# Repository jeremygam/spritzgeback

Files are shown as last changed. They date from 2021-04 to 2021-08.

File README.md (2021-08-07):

# Spritzgeback
A suite of similar custom low profile mechanical keyboards running qmk

Note that this documentation is a work in progress. Will update with more and clean up later






### Basic Information

There are three variants of the spritzgeback keyboard: one with square spacing between keys, one with rectangular spacing between keys, and one with rectangular spacing that uses hotswap sockets.

Square:
Uses three laser-cut case layers plus a PCB layer. All layers are simply stacked so each is visible from the side. This keyboard should be best if using Kailh Choc v2 switches with more 'regular' profile keycaps like DSA, or if you generally prefer wider spacing between keys. Note that if you are using high profile keycaps, the keys may not depress all the way if you include the plate (case layer 3) - it should be fine to leave out layer 3 and just have the PCB as the top layer

Rect:
Uses four laser-cut case layers, with the PCB residing within one of the layers. This keyboard should be best if using Kailh Choc v1 switches with either the Kailh keycaps or MBK keycaps (which measure 16mm in height and 17mm in width).

Hotswap:
Similar to Rect but uses hotswap sockets instead of having switches soldered in place.

### Making a keyboard

If all you want to do is make one of these keyboards, just download the gerber files within the gerber_files directory and the eps files within the case_files directory. You can send the gerber files for production from a PCB manufacturing company. Note that the ".gml" file might need to be renamed to ".gm1" and the ".txt" file might need to be renamed to ".drl" depending on the company. The eps files can be directly sent for laser cutting. Double check that the dimensions are correct before submitting (315.6mm x 96mm for square, 308.9mm x 91.75mm for rect). Also note that the combined thickness of the PCB plus layer 2 should be at least 3mm (preferably a bit more for tolerance) to allow the switch pins adequate space within the case sandwich. For example, with a 1.6mm thick PCB, layer 2 should be at least 1.5mm or so thick. For keyboards where the PCB is totally enclosed in the case (i.e. rect and hotswap), layer 3 should be at least as thick as the PCB so that there isn't a gap between case layers.

Once all components except switches have been soldered, flash the keyboard with qmk (https://beta.docs.qmk.fm/tutorial/newbs_flashing), making sure to short the two "reset" holes while plugging in the PCB. After flashing, test the entire circuit by shorting out the switch holes and making sure the appropriate key is registered. Following that, switches or sockets can then be soldered in. The main step for case assembly is insertion of the threaded inserts into the case layers. If using acrylic, be careful not to crack the layers while inserting the threaded inserts - using the heat from a soldering iron to melt the plastic is highly recommended over using force. If using wood or bamboo layers, a hammer or mallet should be fine. The keyboard can then be screwed together, making sure not to overtighten the screws.

### BOM

Fill in later. See schematic for now

### Requirements

You will need to install and use qmk to flash your keyboard firmware https://qmk.fm/

You will need a footprint file for the USB-C connector Korean Hroparts Elec TYPE-C-31-M-17 from https://www.snapeda.com/parts/TYPE-C-31-M-12/HRO%20Electronics%20Co.,%20Ltd./view-part/

You may also want footprints for Kailh Choc v1 switches (PG1350) from https://github.com/daprice/keyswitches.pretty (also under CC BY-SA 4.0). I modified some of those original footprints to allow for either Choc v1 or v2 switches to be used (see SW_PG1353.kicad_mod and Kailh_socket_PG1353.kicad_mod in the JJG.pretty directory).

### Other Information

For info on how to design your own keyboard, check out Hadi's youtube channel (https://www.youtube.com/playlist?list=PLbtY7JsOJDYkHNuTmBtGgaWv_qipKeL-u) or Masterzen's tutorial (https://www.masterzen.fr/2020/05/03/designing-a-keyboard-part-1/)

Note that since each of the spritzgeback variants are highly similar electrically, they can all use the same qmk files

Note that if you make your own case files, ponoko recommends saving in eps file format with units set to mm instead of points.

------------------------



This work is licensed under a [Creative Commons Attribution-ShareAlike 4.0 International License](http://creativecommons.org/licenses/by-sa/4.0/).

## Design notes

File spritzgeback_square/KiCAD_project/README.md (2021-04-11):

note that I wanted to rename the project from CHOCOBOard to spritzgeback, but KiCAD doesn't handle renaming easily so I've kept the original name here

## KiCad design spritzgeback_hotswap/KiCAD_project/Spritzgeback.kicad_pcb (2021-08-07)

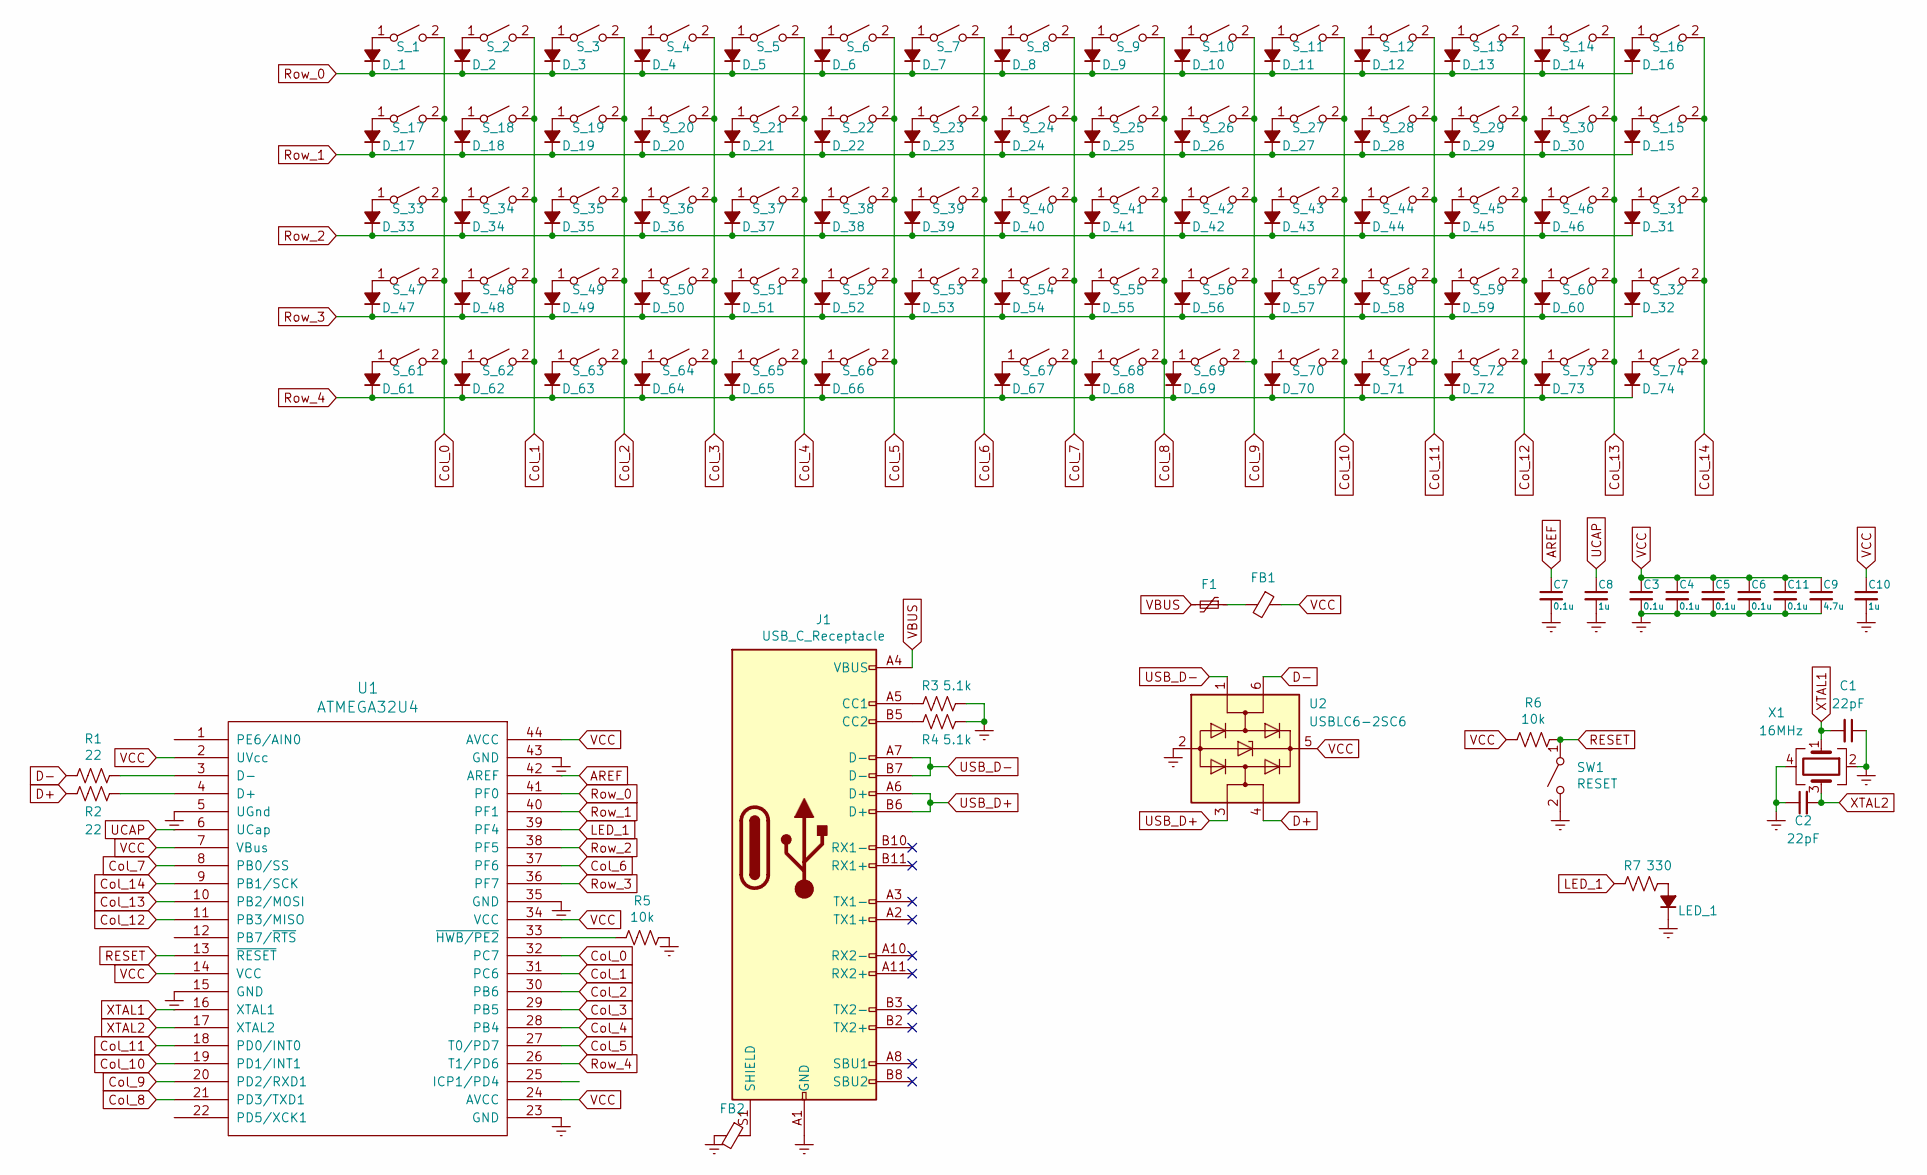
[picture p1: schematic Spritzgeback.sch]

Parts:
C1, C2: 22pF; C_0805_2012Metric_Pad1.18x1.45mm_HandSolder
C3, C4, C5, C6, C7, C11: 0.1u; C_0805_2012Metric_Pad1.18x1.45mm_HandSolder
C8, C10: 1u; C_0805_2012Metric_Pad1.18x1.45mm_HandSolder
C9: 4.7u; C_0805_2012Metric_Pad1.18x1.45mm_HandSolder
D_1, D_2, D_3, D_4, D_5, D_6, D_7, D_8, D_9, D_10, D_11, D_12, D_13, D_14, D_15, D_16, D_17, D_18, D_19, D_20, D_21, D_22, D_23, D_24, D_25, D_26, D_27, D_28, D_29, D_30, D_31, D_32, D_33, D_34, D_35, D_36, D_37, D_38, D_39, D_40, D_41, D_42, D_43, D_44, D_45, D_46, D_47, D_48, D_49, D_50, D_51, D_52, D_53, D_54, D_55, D_56, D_57, D_58, D_59, D_60, D_61, D_62, D_63, D_64, D_65, D_66, D_67, D_68, D_69, D_70, D_71, D_72, D_73, D_74: D_Small_ALT; D_SOD-123_silk
F1: Polyfuse_Small; R_0805_2012Metric
FB1, FB2: Ferrite_Bead_Small; R_0805_2012Metric
J1: USB_C_Receptacle; HRO_TYPE-C-31-M-12
LED_1: D_Small_ALT; LED_0805_2012Metric
R1, R2: 22; R_0805_2012Metric_Pad1.20x1.40mm_HandSolder
R3, R4: 5.1k; R_0805_2012Metric
R5, R6: 10k; R_0805_2012Metric_Pad1.20x1.40mm_HandSolder
R7: 330; R_0805_2012Metric_Pad1.20x1.40mm_HandSolder
SW1: RESET; reset_holes
S_1, S_2, S_3, S_4, S_5, S_6, S_7, S_8, S_9, S_10, S_11, S_12, S_13, S_14, S_15, S_16, S_17, S_18, S_19, S_20, S_21, S_22, S_23, S_24, S_25, S_26, S_27, S_28, S_29, S_30, S_31, S_32, S_33, S_34, S_35, S_36, S_37, S_38, S_39, S_40, S_41, S_42, S_43, S_44, S_45, S_46, S_47, S_48, S_49, S_50, S_51, S_52, S_53, S_54, S_55, S_56, S_57, S_58, S_59, S_60, S_61, S_62, S_63, S_64, S_65, S_66, S_67, S_68, S_69, S_70, S_71, S_72, S_73, S_74: SW_SPST; Kailh_socket_PG1353
U1: ATMEGA32U4; TQFP-44_10x10mm_P0.8mm
U2: USBLC6-2SC6; SOT-23-6
X1: 16MHz; Crystal_SMD_3225-4Pin_3.2x2.5mm

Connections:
AREF: C7.1, U1.42 (AREF)
Col_0: S_1.2 (B), S_17.2 (B), S_33.2 (B), S_47.2 (B), S_61.2 (B), U1.32 (PC7)
Col_1: S_2.2 (B), S_18.2 (B), S_34.2 (B), S_48.2 (B), S_62.2 (B), U1.31 (PC6)
Col_2: S_3.2 (B), S_19.2 (B), S_35.2 (B), S_49.2 (B), S_63.2 (B), U1.30 (PB6)
Col_3: S_4.2 (B), S_20.2 (B), S_36.2 (B), S_50.2 (B), S_64.2 (B), U1.29 (PB5)
Col_4: S_5.2 (B), S_21.2 (B), S_37.2 (B), S_51.2 (B), S_65.2 (B), U1.28 (PB4)
Col_5: S_6.2 (B), S_22.2 (B), S_38.2 (B), S_52.2 (B), S_66.2 (B), U1.27 (T0/PD7)
Col_6: S_7.2 (B), S_23.2 (B), S_39.2 (B), S_53.2 (B), U1.37 (PF6)
Col_7: S_8.2 (B), S_24.2 (B), S_40.2 (B), S_54.2 (B), S_67.2 (B), U1.8 (PB0/SS)
Col_8: S_9.2 (B), S_25.2 (B), S_41.2 (B), S_55.2 (B), S_68.2 (B), U1.21 (PD3/TXD1)
Col_9: S_10.2 (B), S_26.2 (B), S_42.2 (B), S_56.2 (B), S_69.2 (B), U1.20 (PD2/RXD1)
Col_10: S_11.2 (B), S_27.2 (B), S_43.2 (B), S_57.2 (B), S_70.2 (B), U1.19 (PD1/INT1)
Col_11: S_12.2 (B), S_28.2 (B), S_44.2 (B), S_58.2 (B), S_71.2 (B), U1.18 (PD0/INT0)
Col_12: S_13.2 (B), S_29.2 (B), S_45.2 (B), S_59.2 (B), S_72.2 (B), U1.11 (PB3/MISO)
Col_13: S_14.2 (B), S_30.2 (B), S_46.2 (B), S_60.2 (B), S_73.2 (B), U1.10 (PB2/MOSI)
Col_14: S_15.2 (B), S_16.2 (B), S_31.2 (B), S_32.2 (B), S_74.2 (B), U1.9 (PB1/SCK)
D+: R2.2, U2.4 (I/O2)
D-: R1.2, U2.6 (I/O1)
Earth: C1.1, C2.1, C3.2, C4.2, C5.2, C6.2, C7.2, C8.2, C9.2, C10.2, C11.2, FB2.2, J1.A1 (GND), J1.A12 (GND), J1.B1 (GND), J1.B12 (GND), LED_1.1 (K), R3.1, R4.1, R5.1, SW1.2 (B), U1.5 (UGnd), U1.15 (GND), U1.23 (GND), U1.35 (GND), U1.43 (GND), U2.2 (GND), X1.2, X1.4; also elsewhere on the board
LED_1: R7.2, U1.39 (PF4)
unnamed: D_1.2 (A), S_1.1 (A)
unnamed: D_2.2 (A), S_2.1 (A)
unnamed: D_3.2 (A), S_3.1 (A)
unnamed: D_4.2 (A), S_4.1 (A)
unnamed: D_5.2 (A), S_5.1 (A)
unnamed: D_6.2 (A), S_6.1 (A)
unnamed: D_7.2 (A), S_7.1 (A)
unnamed: D_8.2 (A), S_8.1 (A)
unnamed: D_9.2 (A), S_9.1 (A)
unnamed: D_10.2 (A), S_10.1 (A)
unnamed: D_11.2 (A), S_11.1 (A)
unnamed: D_12.2 (A), S_12.1 (A)
unnamed: D_13.2 (A), S_13.1 (A)
unnamed: D_14.2 (A), S_14.1 (A)
unnamed: D_15.2 (A), S_15.1 (A)
unnamed: D_16.2 (A), S_16.1 (A)
unnamed: D_17.2 (A), S_17.1 (A)
unnamed: D_18.2 (A), S_18.1 (A)
unnamed: D_19.2 (A), S_19.1 (A)
unnamed: D_20.2 (A), S_20.1 (A)
unnamed: D_21.2 (A), S_21.1 (A)
unnamed: D_22.2 (A), S_22.1 (A)
unnamed: D_23.2 (A), S_23.1 (A)
unnamed: D_24.2 (A), S_24.1 (A)
unnamed: D_25.2 (A), S_25.1 (A)
unnamed: D_26.2 (A), S_26.1 (A)
unnamed: D_27.2 (A), S_27.1 (A)
unnamed: D_28.2 (A), S_28.1 (A)
unnamed: D_29.2 (A), S_29.1 (A)
unnamed: D_30.2 (A), S_30.1 (A)
unnamed: D_31.2 (A), S_31.1 (A)
unnamed: D_32.2 (A), S_32.1 (A)
unnamed: D_33.2 (A), S_33.1 (A)
unnamed: D_34.2 (A), S_34.1 (A)
unnamed: D_35.2 (A), S_35.1 (A)
unnamed: D_36.2 (A), S_36.1 (A)
unnamed: D_37.2 (A), S_37.1 (A)
unnamed: D_38.2 (A), S_38.1 (A)
unnamed: D_39.2 (A), S_39.1 (A)
unnamed: D_40.2 (A), S_40.1 (A)
unnamed: D_41.2 (A), S_41.1 (A)
unnamed: D_42.2 (A), S_42.1 (A)
unnamed: D_43.2 (A), S_43.1 (A)
unnamed: D_44.2 (A), S_44.1 (A)
unnamed: D_45.2 (A), S_45.1 (A)
unnamed: D_46.2 (A), S_46.1 (A)
unnamed: D_47.2 (A), S_47.1 (A)
unnamed: D_48.2 (A), S_48.1 (A)
unnamed: D_49.2 (A), S_49.1 (A)
unnamed: D_50.2 (A), S_50.1 (A)
unnamed: D_51.2 (A), S_51.1 (A)
unnamed: D_52.2 (A), S_52.1 (A)
unnamed: D_53.2 (A), S_53.1 (A)
unnamed: D_54.2 (A), S_54.1 (A)
unnamed: D_55.2 (A), S_55.1 (A)
unnamed: D_56.2 (A), S_56.1 (A)
unnamed: D_57.2 (A), S_57.1 (A)
unnamed: D_58.2 (A), S_58.1 (A)
unnamed: D_59.2 (A), S_59.1 (A)
unnamed: D_60.2 (A), S_60.1 (A)
unnamed: D_61.2 (A), S_61.1 (A)
unnamed: D_62.2 (A), S_62.1 (A)
unnamed: D_63.2 (A), S_63.1 (A)
unnamed: D_64.2 (A), S_64.1 (A)
unnamed: D_65.2 (A), S_65.1 (A)
unnamed: D_66.2 (A), S_66.1 (A)
unnamed: D_67.2 (A), S_67.1 (A)
unnamed: D_68.2 (A), S_68.1 (A)
unnamed: D_69.2 (A), S_69.1 (A)
unnamed: D_70.2 (A), S_70.1 (A)
unnamed: D_71.2 (A), S_71.1 (A)
unnamed: D_72.2 (A), S_72.1 (A)
unnamed: D_73.2 (A), S_73.1 (A)
unnamed: D_74.2 (A), S_74.1 (A)
unnamed: F1.1, FB1.2
unnamed: FB2.1, J1.S1 (SHIELD)
unnamed: J1.A5 (CC1), R3.2
unnamed: J1.B5 (CC2), R4.2
unnamed: LED_1.2 (A), R7.1
unnamed: R1.1, U1.3 (D-)
unnamed: R2.1, U1.4 (D+)
unnamed: R5.2, U1.33 (~HWB/PE2)
RESET: R6.1, SW1.1 (A), U1.13 (~RESET); also elsewhere on the board
Row_0: D_1.1 (K), D_2.1 (K), D_3.1 (K), D_4.1 (K), D_5.1 (K), D_6.1 (K), D_7.1 (K), D_8.1 (K), D_9.1 (K), D_10.1 (K), D_11.1 (K), D_12.1 (K), D_13.1 (K), D_14.1 (K), D_16.1 (K), U1.41 (PF0)
Row_1: D_15.1 (K), D_17.1 (K), D_18.1 (K), D_19.1 (K), D_20.1 (K), D_21.1 (K), D_22.1 (K), D_23.1 (K), D_24.1 (K), D_25.1 (K), D_26.1 (K), D_27.1 (K), D_28.1 (K), D_29.1 (K), D_30.1 (K), U1.40 (PF1)
Row_2: D_31.1 (K), D_33.1 (K), D_34.1 (K), D_35.1 (K), D_36.1 (K), D_37.1 (K), D_38.1 (K), D_39.1 (K), D_40.1 (K), D_41.1 (K), D_42.1 (K), D_43.1 (K), D_44.1 (K), D_45.1 (K), D_46.1 (K), U1.38 (PF5)
Row_3: D_32.1 (K), D_47.1 (K), D_48.1 (K), D_49.1 (K), D_50.1 (K), D_51.1 (K), D_52.1 (K), D_53.1 (K), D_54.1 (K), D_55.1 (K), D_56.1 (K), D_57.1 (K), D_58.1 (K), D_59.1 (K), D_60.1 (K), U1.36 (PF7)
Row_4: D_61.1 (K), D_62.1 (K), D_63.1 (K), D_64.1 (K), D_65.1 (K), D_66.1 (K), D_67.1 (K), D_68.1 (K), D_69.1 (K), D_70.1 (K), D_71.1 (K), D_72.1 (K), D_73.1 (K), D_74.1 (K), U1.26 (T1/PD6)
UCAP: C8.1, U1.6 (UCap)
USB_D+: J1.A6 (D+), J1.B6 (D+), U2.3 (I/O2)
USB_D-: J1.A7 (D-), J1.B7 (D-), U2.1 (I/O1)
VBUS: F1.2, J1.A4 (VBUS), J1.A9 (VBUS), J1.B4 (VBUS), J1.B9 (VBUS)
VCC: C3.1, C4.1, C5.1, C6.1, C9.1, C10.1, C11.1, FB1.1, R6.2, U1.2 (UVcc), U1.7 (VBus), U1.14 (VCC), U1.24 (AVCC), U1.34 (VCC), U1.44 (AVCC), U2.5 (VBUS)
XTAL1: C1.2, U1.16 (XTAL1), X1.1
XTAL2: C2.2, U1.17 (XTAL2), X1.3

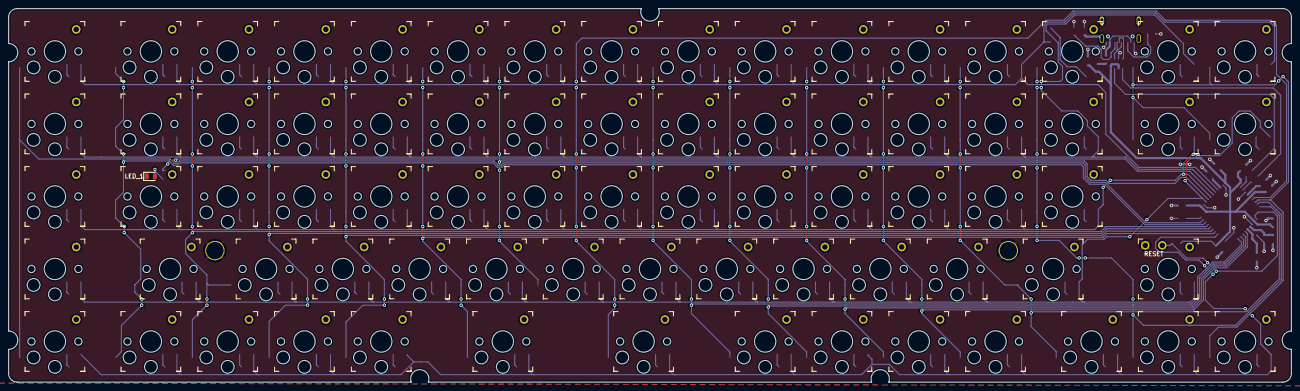
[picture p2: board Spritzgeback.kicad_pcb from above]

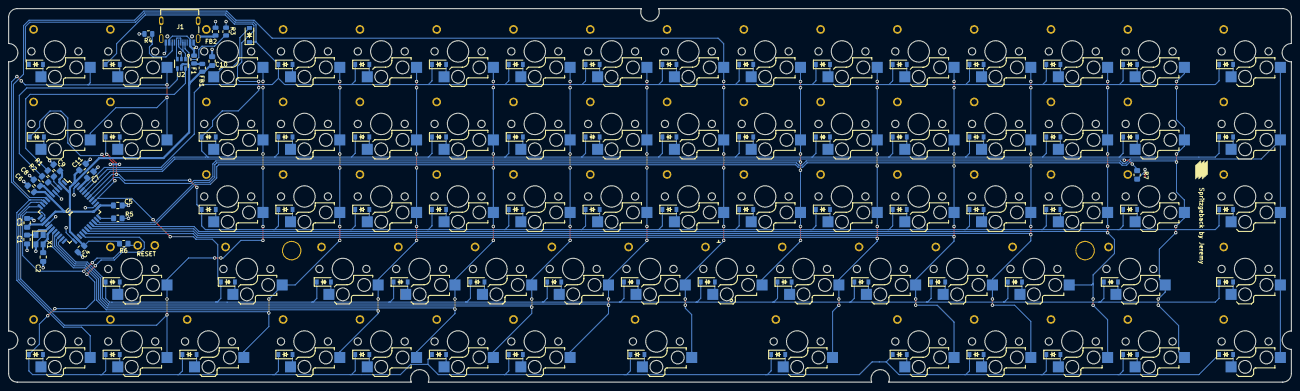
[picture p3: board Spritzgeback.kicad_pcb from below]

Board: 2 copper layers, 300.7 x 87.6 mm, 175 parts (99 on the bottom side), 115 nets.

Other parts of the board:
RESET: RESET; reset_holes

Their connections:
Earth: RESET.2; also elsewhere on the board
RESET: RESET.1; also elsewhere on the board

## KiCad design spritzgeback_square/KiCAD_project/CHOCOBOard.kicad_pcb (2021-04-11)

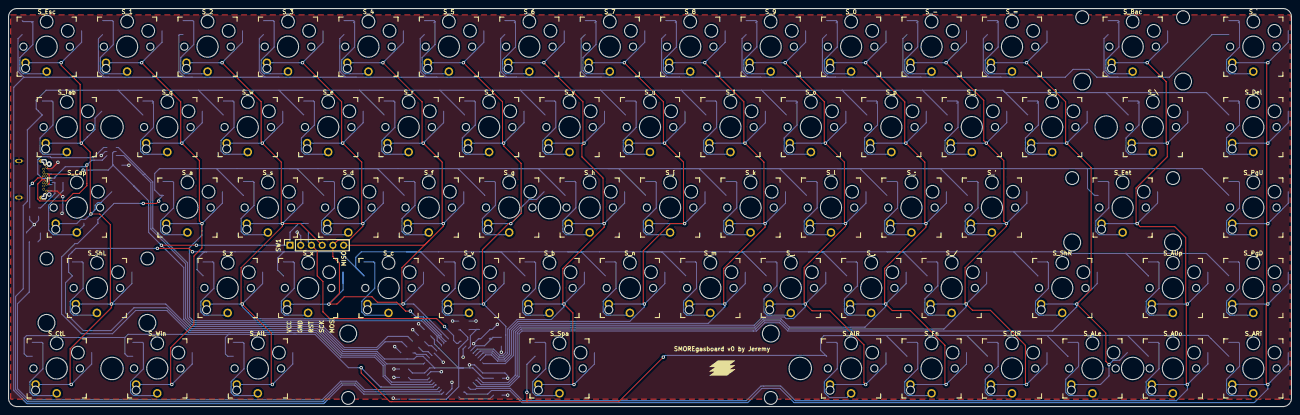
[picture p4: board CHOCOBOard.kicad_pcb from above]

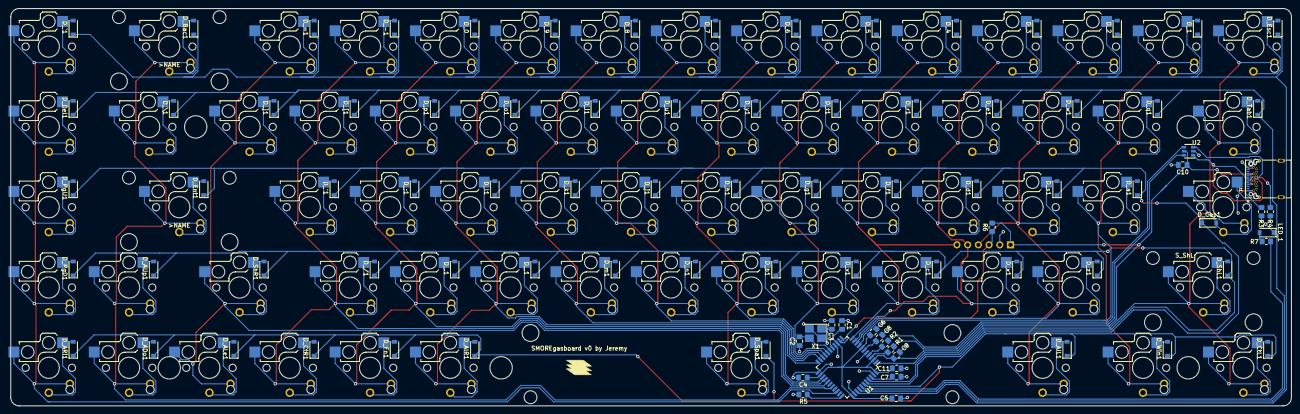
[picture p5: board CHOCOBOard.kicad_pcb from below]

Board: 2 copper layers, 303.8 x 94.2 mm, 163 parts (91 on the bottom side), 106 nets.

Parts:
>NAME: >VALUE; stabilizer_holes_200
>NAME#2: >VALUE; stabilizer_holes_225
C1, C2: 22pF; C_0805_2012Metric_Pad1.18x1.45mm_HandSolder
C3, C4, C5, C6, C7, C11: 0.1u; C_0805_2012Metric_Pad1.18x1.45mm_HandSolder
C8, C10: 1u; C_0805_2012Metric_Pad1.18x1.45mm_HandSolder
C9: 4.7u; C_0805_2012Metric_Pad1.18x1.45mm_HandSolder
D_0, D_1, D_2, D_3, D_4, D_5, D_6, D_7, D_8, D_9, D_.1: D_Small_ALT; D_SOD-123
D_'1: D_Small_ALT; D_SOD-123
D_,1: D_Small_ALT; D_SOD-123
D_-1: D_Small_ALT; D_SOD-123
D_/1: D_Small_ALT; D_SOD-123
D_;1: D_Small_ALT; D_SOD-123
D_=1: D_Small_ALT; D_SOD-123
D_ADo1: D_Small_ALT; D_SOD-123
D_ALe1: D_Small_ALT; D_SOD-123
D_ARi1: D_Small_ALT; D_SOD-123
D_AUp1: D_Small_ALT; D_SOD-123
D_AlL1: D_Small_ALT; D_SOD-123
D_AlR1: D_Small_ALT; D_SOD-123
D_Bac1: D_Small_ALT; D_SOD-123
D_Cap1: D_Small_ALT; D_SOD-123
D_CtL1: D_Small_ALT; D_SOD-123
D_CtR1: D_Small_ALT; D_SOD-123
D_Del1: D_Small_ALT; D_SOD-123
D_Ent1: D_Small_ALT; D_SOD-123
D_Esc1: D_Small_ALT; D_SOD-123
D_Fn1: D_Small_ALT; D_SOD-123
D_PgD1: D_Small_ALT; D_SOD-123
D_PgU1: D_Small_ALT; D_SOD-123
D_ShL1: D_Small_ALT; D_SOD-123
D_ShR1: D_Small_ALT; D_SOD-123
D_Spa1: D_Small_ALT; D_SOD-123
D_Tab1: D_Small_ALT; D_SOD-123
D_Win1: D_Small_ALT; D_SOD-123
D_[1: D_Small_ALT; D_SOD-123
D_\1: D_Small_ALT; D_SOD-123
D_]1: D_Small_ALT; D_SOD-123
D_`1: D_Small_ALT; D_SOD-123
D_a1: D_Small_ALT; D_SOD-123
D_b1: D_Small_ALT; D_SOD-123
D_c1: D_Small_ALT; D_SOD-123
D_d1: D_Small_ALT; D_SOD-123
D_e1: D_Small_ALT; D_SOD-123
D_f1: D_Small_ALT; D_SOD-123
D_g1: D_Small_ALT; D_SOD-123
D_h1: D_Small_ALT; D_SOD-123
D_i1: D_Small_ALT; D_SOD-123
D_j1: D_Small_ALT; D_SOD-123
D_k1: D_Small_ALT; D_SOD-123
D_l1: D_Small_ALT; D_SOD-123
D_m1: D_Small_ALT; D_SOD-123
D_n1: D_Small_ALT; D_SOD-123
D_o1: D_Small_ALT; D_SOD-123
D_p1: D_Small_ALT; D_SOD-123
D_q1: D_Small_ALT; D_SOD-123
D_r1: D_Small_ALT; D_SOD-123
D_s1: D_Small_ALT; D_SOD-123
D_t1: D_Small_ALT; D_SOD-123
D_u1: D_Small_ALT; D_SOD-123
D_v1: D_Small_ALT; D_SOD-123
D_w1: D_Small_ALT; D_SOD-123
D_x1: D_Small_ALT; D_SOD-123
D_y1: D_Small_ALT; D_SOD-123
D_z1: D_Small_ALT; D_SOD-123
J1: USB_C_Receptacle; CUI_UJ31-CH-31-SMT-TR
LED_1: D_Small_ALT; D_SOD-123
R1, R2: 22; R_0805_2012Metric_Pad1.20x1.40mm_HandSolder
R3, R4: 5.1k; R_0805_2012Metric_Pad1.20x1.40mm_HandSolder
R5, R6: 10k; R_0805_2012Metric_Pad1.20x1.40mm_HandSolder
R7: 330; R_0805_2012Metric_Pad1.20x1.40mm_HandSolder
SW1: RESET; PinSocket_1x06_P2.54mm_Vertical
S_0, S_1, S_2, S_3, S_4, S_5, S_6, S_7, S_8, S_9, S_.: SW_SPST; Kailh_socket_PG1353_solder_PG1350
S_': SW_SPST; Kailh_socket_PG1353_solder_PG1350
S_,: SW_SPST; Kailh_socket_PG1353_solder_PG1350
S_-: SW_SPST; Kailh_socket_PG1353_solder_PG1350
S_/: SW_SPST; Kailh_socket_PG1353_solder_PG1350
S_;: SW_SPST; Kailh_socket_PG1353_solder_PG1350
S_=: SW_SPST; Kailh_socket_PG1353_solder_PG1350
S_ADo: SW_SPST; Kailh_socket_PG1353_solder_PG1350
S_ALe: SW_SPST; Kailh_socket_PG1353_solder_PG1350
S_ARi: SW_SPST; Kailh_socket_PG1353_solder_PG1350
S_AUp: SW_SPST; Kailh_socket_PG1353_solder_PG1350
S_AlL: SW_SPST; Kailh_socket_PG1353_solder_PG1350
S_AlR: SW_SPST; Kailh_socket_PG1353_solder_PG1350
S_Bac: SW_SPST; Kailh_socket_PG1353_solder_PG1350
S_Cap: SW_SPST; Kailh_socket_PG1353_solder_PG1350
S_CtL: SW_SPST; Kailh_socket_PG1353_solder_PG1350
S_CtR: SW_SPST; Kailh_socket_PG1353_solder_PG1350
S_Del: SW_SPST; Kailh_socket_PG1353_solder_PG1350
S_Ent: SW_SPST; Kailh_socket_PG1353_solder_PG1350
S_Esc: SW_SPST; Kailh_socket_PG1353_solder_PG1350
S_Fn: SW_SPST; Kailh_socket_PG1353_solder_PG1350
S_PgD: SW_SPST; Kailh_socket_PG1353_solder_PG1350
S_PgU: SW_SPST; Kailh_socket_PG1353_solder_PG1350
S_ShL: SW_SPST; Kailh_socket_PG1353_solder_PG1350
S_ShR: SW_SPST; Kailh_socket_PG1353_solder_PG1350
S_Spa: SW_SPST; Kailh_socket_PG1353_solder_PG1350
S_Tab: SW_SPST; Kailh_socket_PG1353_solder_PG1350
S_Win: SW_SPST; Kailh_socket_PG1353_solder_PG1350
S_[: SW_SPST; Kailh_socket_PG1353_solder_PG1350
S_\: SW_SPST; Kailh_socket_PG1353_solder_PG1350
S_]: SW_SPST; Kailh_socket_PG1353_solder_PG1350
S_`: SW_SPST; Kailh_socket_PG1353_solder_PG1350
S_a: SW_SPST; Kailh_socket_PG1353_solder_PG1350
S_b: SW_SPST; Kailh_socket_PG1353_solder_PG1350
S_c: SW_SPST; Kailh_socket_PG1353_solder_PG1350
S_d: SW_SPST; Kailh_socket_PG1353_solder_PG1350
S_e: SW_SPST; Kailh_socket_PG1353_solder_PG1350
S_f: SW_SPST; Kailh_socket_PG1353_solder_PG1350
S_g: SW_SPST; Kailh_socket_PG1353_solder_PG1350
S_h: SW_SPST; Kailh_socket_PG1353_solder_PG1350
S_i: SW_SPST; Kailh_socket_PG1353_solder_PG1350
S_j: SW_SPST; Kailh_socket_PG1353_solder_PG1350
S_k: SW_SPST; Kailh_socket_PG1353_solder_PG1350
S_l: SW_SPST; Kailh_socket_PG1353_solder_PG1350
S_m: SW_SPST; Kailh_socket_PG1353_solder_PG1350
S_n: SW_SPST; Kailh_socket_PG1353_solder_PG1350
S_o: SW_SPST; Kailh_socket_PG1353_solder_PG1350
S_p: SW_SPST; Kailh_socket_PG1353_solder_PG1350
S_q: SW_SPST; Kailh_socket_PG1353_solder_PG1350
S_r: SW_SPST; Kailh_socket_PG1353_solder_PG1350
S_s: SW_SPST; Kailh_socket_PG1353_solder_PG1350
S_t: SW_SPST; Kailh_socket_PG1353_solder_PG1350
S_u: SW_SPST; Kailh_socket_PG1353_solder_PG1350
S_v: SW_SPST; Kailh_socket_PG1353_solder_PG1350
S_w: SW_SPST; Kailh_socket_PG1353_solder_PG1350
S_x: SW_SPST; Kailh_socket_PG1353_solder_PG1350
S_y: SW_SPST; Kailh_socket_PG1353_solder_PG1350
S_z: SW_SPST; Kailh_socket_PG1353_solder_PG1350
U1: ATMEGA32U4; TQFP-44_10x10mm_P0.8mm
U2: USBLC6-2SC6; SOT-23-6
X1: 16MHz; Crystal_SMD_SeikoEpson_FA238-4Pin_3.2x2.5mm_HandSoldering
e: >VALUE; stabilizer_holes_625

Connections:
AREF: C7.1, U1.42
Col_0: S_Cap.2, S_CtL.2, S_Esc.2, S_ShL.2, S_Tab.2, U1.1
Col_1: S_1.2, S_Win.2, S_a.2, S_q.2, U1.8
Col_2: SW1.4, S_2.2, S_AlL.2, S_s.2, S_w.2, S_z.2, U1.9
Col_3: SW1.5, S_3.2, S_d.2, S_e.2, S_x.2, U1.10
Col_4: SW1.6, S_4.2, S_c.2, S_f.2, S_r.2, U1.11
Col_5: S_5.2, S_g.2, S_t.2, S_v.2, U1.18
Col_6: S_6.2, S_Spa.2, S_b.2, S_h.2, S_y.2, U1.19
Col_7: S_7.2, S_j.2, S_n.2, S_u.2, U1.20
Col_8: S_8.2, S_i.2, S_k.2, S_m.2, U1.21
Col_9: S_9.2, S_,.2, S_AlR.2, S_l.2, S_o.2, U1.22
Col_10: S_0.2, S_..2, S_;.2, S_Fn.2, S_p.2, U1.25
Col_11: S_'.2, S_-.2, S_/.2, S_CtR.2, S_[.2, U1.26
Col_12: S_=.2, S_ALe.2, S_ShR.2, S_].2, U1.27
Col_13: S_ADo.2, S_AUp.2, S_Bac.2, S_Ent.2, S_\.2, U1.29
Col_14: S_ARi.2, S_Del.2, S_PgD.2, S_PgU.2, S_`.2, U1.31
D+: R2.2, U2.4
D-: R1.2, U2.6
Earth: C1.1, C2.1, C3.2, C4.2, C5.2, C6.2, C7.2, C8.2, C9.2, C10.2, C11.2, J1.A1, J1.A12, J1.B1, J1.B12, J1.S1, J1.S2, J1.S3, J1.S4, J1.S5, J1.S6, LED_1.1, R3.1, R4.1, R5.1, SW1.2, U1.5, U1.15, U1.23, U1.35, U1.43, U2.2, X1.2, X1.4
LED_1: R7.2, U1.38
unnamed: D_0.2, S_0.1
unnamed: D_1.2, S_1.1
unnamed: D_2.2, S_2.1
unnamed: D_3.2, S_3.1
unnamed: D_4.2, S_4.1
unnamed: D_5.2, S_5.1
unnamed: D_6.2, S_6.1
unnamed: D_7.2, S_7.1
unnamed: D_8.2, S_8.1
unnamed: D_9.2, S_9.1
unnamed: D_'1.2, S_'.1
unnamed: D_,1.2, S_,.1
unnamed: D_-1.2, S_-.1
unnamed: D_.1.2, S_..1
unnamed: D_/1.2, S_/.1
unnamed: D_;1.2, S_;.1
unnamed: D_=1.2, S_=.1
unnamed: D_ADo1.2, S_ADo.1
unnamed: D_ALe1.2, S_ALe.1
unnamed: D_ARi1.2, S_ARi.1
unnamed: D_AUp1.2, S_AUp.1
unnamed: D_AlL1.2, S_AlL.1
unnamed: D_AlR1.2, S_AlR.1
unnamed: D_Bac1.2, S_Bac.1
unnamed: D_Cap1.2, S_Cap.1
unnamed: D_CtL1.2, S_CtL.1
unnamed: D_CtR1.2, S_CtR.1
unnamed: D_Del1.2, S_Del.1
unnamed: D_Ent1.2, S_Ent.1
unnamed: D_Esc1.2, S_Esc.1
unnamed: D_Fn1.2, S_Fn.1
unnamed: D_PgD1.2, S_PgD.1
unnamed: D_PgU1.2, S_PgU.1
unnamed: D_ShL1.2, S_ShL.1
unnamed: D_ShR1.2, S_ShR.1
unnamed: D_Spa1.2, S_Spa.1
unnamed: D_Tab1.2, S_Tab.1
unnamed: D_Win1.2, S_Win.1
unnamed: D_[1.2, S_[.1
unnamed: D_\1.2, S_\.1
unnamed: D_]1.2, S_].1
unnamed: D_`1.2, S_`.1
unnamed: D_a1.2, S_a.1
unnamed: D_b1.2, S_b.1
unnamed: D_c1.2, S_c.1
unnamed: D_d1.2, S_d.1
unnamed: D_e1.2, S_e.1
unnamed: D_f1.2, S_f.1
unnamed: D_g1.2, S_g.1
unnamed: D_h1.2, S_h.1
unnamed: D_i1.2, S_i.1
unnamed: D_j1.2, S_j.1
unnamed: D_k1.2, S_k.1
unnamed: D_l1.2, S_l.1
unnamed: D_m1.2, S_m.1
unnamed: D_n1.2, S_n.1
unnamed: D_o1.2, S_o.1
unnamed: D_p1.2, S_p.1
unnamed: D_q1.2, S_q.1
unnamed: D_r1.2, S_r.1
unnamed: D_s1.2, S_s.1
unnamed: D_t1.2, S_t.1
unnamed: D_u1.2, S_u.1
unnamed: D_v1.2, S_v.1
unnamed: D_w1.2, S_w.1
unnamed: D_x1.2, S_x.1
unnamed: D_y1.2, S_y.1
unnamed: D_z1.2, S_z.1
unnamed: J1.A5, R3.2
unnamed: J1.B5, R4.2
unnamed: LED_1.2, R7.1
unnamed: R1.1, U1.3
unnamed: R2.1, U1.4
unnamed: R5.2, U1.33
RESET: R6.1, SW1.3, U1.13
Row_0: D_0.1, D_1.1, D_2.1, D_3.1, D_4.1, D_5.1, D_6.1, D_7.1, D_8.1, D_9.1, D_-1.1, D_=1.1, D_Bac1.1, D_Esc1.1, D_`1.1, U1.36
Row_1: D_Del1.1, D_Tab1.1, D_[1.1, D_\1.1, D_]1.1, D_e1.1, D_i1.1, D_o1.1, D_p1.1, D_q1.1, D_r1.1, D_t1.1, D_u1.1, D_w1.1, D_y1.1, U1.37
Row_2: D_'1.1, D_;1.1, D_Cap1.1, D_Ent1.1, D_PgU1.1, D_a1.1, D_d1.1, D_f1.1, D_g1.1, D_h1.1, D_j1.1, D_k1.1, D_l1.1, D_s1.1, U1.40
Row_3: D_,1.1, D_.1.1, D_/1.1, D_AUp1.1, D_PgD1.1, D_ShL1.1, D_ShR1.1, D_b1.1, D_c1.1, D_m1.1, D_n1.1, D_v1.1, D_x1.1, D_z1.1, U1.41
Row_4: D_ADo1.1, D_ALe1.1, D_ARi1.1, D_AlL1.1, D_AlR1.1, D_CtL1.1, D_CtR1.1, D_Fn1.1, D_Spa1.1, D_Win1.1, U1.39
UCAP: C8.1, U1.6
USB_D+: J1.A6, J1.B6, U2.3
USB_D-: J1.A7, J1.B7, U2.1
VBUS: C3.1, C4.1, C5.1, C6.1, C9.1, C10.1, C11.1, J1.A4, J1.A9, J1.B4, J1.B9, R6.2, SW1.1, U1.2, U1.7, U1.14, U1.24, U1.34, U1.44, U2.5
XTAL1: C1.2, U1.16, X1.1
XTAL2: C2.2, U1.17, X1.3

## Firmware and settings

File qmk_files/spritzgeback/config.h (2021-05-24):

#ifndef CONFIG_H
#define CONFIG_H

#include "config_common.h"

/* USB Device descriptor parameter */
#define VENDOR_ID       0xFEED
#define PRODUCT_ID      0x6060
#define DEVICE_VER      0x0001
#define MANUFACTURER    qmkbuilder
#define PRODUCT         keyboard
#define DESCRIPTION     Keyboard

/* key matrix size */
#define MATRIX_ROWS 5
#define MATRIX_COLS 15

/* key matrix pins */
#define MATRIX_ROW_PINS { F0, F1, F5, F7, D6 }
#define MATRIX_COL_PINS { C7, C6, B6, B5, B4, D7, F6, B0, D3, D2, D1, D0, B3, B2, B1 }
#define UNUSED_PINS

/* COL2ROW or ROW2COL */
#define DIODE_DIRECTION COL2ROW

/* number of backlight levels */

#ifdef BACKLIGHT_PIN
#define BACKLIGHT_LEVELS 3
#endif

/* Set 0 if debouncing isn't needed */
#define DEBOUNCING_DELAY 5

/* Mechanical locking support. Use KC_LCAP, KC_LNUM or KC_LSCR instead in keymap */
#define LOCKING_SUPPORT_ENABLE

/* Locking resynchronize hack */
#define LOCKING_RESYNC_ENABLE

/* key combination for command */
#define IS_COMMAND() ( \
    keyboard_report->mods == (MOD_BIT(KC_LSHIFT) | MOD_BIT(KC_RSHIFT)) \
)

/* prevent stuck modifiers */
#define PREVENT_STUCK_MODIFIERS

/* Tap Dance Delay */
#define TAPPING_TERM 300

#ifdef RGB_DI_PIN
#define RGBLIGHT_ANIMATIONS
#define RGBLED_NUM 0
#define RGBLIGHT_HUE_STEP 8
#define RGBLIGHT_SAT_STEP 8
#define RGBLIGHT_VAL_STEP 8
#endif

#endif

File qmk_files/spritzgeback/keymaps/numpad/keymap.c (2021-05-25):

#include "spritzgeback.h"

const uint16_t PROGMEM keymaps[][MATRIX_ROWS][MATRIX_COLS] = {

	KEYMAP(
		KC_ESC, KC_1, KC_2, KC_3, KC_4, KC_5, KC_6, KC_7, KC_8, KC_9, KC_0, KC_MINS, KC_EQL, KC_BSPC, KC_END,
		KC_GRV, KC_TAB, KC_Q, KC_W, KC_E, KC_R, KC_T, KC_Y, KC_U, KC_I, KC_O, KC_P, KC_LBRC, KC_RBRC, KC_HOME, 
		KC_BSLS, KC_CAPS, KC_A, KC_S, KC_D, KC_F, KC_G, KC_H, KC_J, KC_K, KC_L, KC_SCLN, KC_QUOT, KC_ENT, KC_DEL,
		TD(0), KC_LSFT, KC_Z, KC_X, KC_C, KC_V, KC_B, KC_N, KC_M, KC_COMM, KC_DOT, KC_SLSH, KC_RSFT, KC_UP, KC_PSCR,
		TD(1), KC_LCTL, KC_LGUI, TG(1), KC_LALT, KC_SPC, KC_SPC, KC_VOLD, KC_MPLY, KC_VOLU, KC_RCTL, KC_LEFT, KC_DOWN, KC_RGHT),

	KEYMAP(
		KC_TRNS, KC_NO, KC_NO, KC_7, KC_8, KC_9, KC_NO, KC_NO, KC_7, KC_8, KC_9, KC_NO, KC_NO, KC_BSPC, KC_TRNS,
		KC_TRNS, KC_NO, KC_NO, KC_4, KC_5, KC_6, KC_LPRN, KC_RPRN, KC_4, KC_5, KC_6, KC_NO, KC_LPRN, KC_RPRN, KC_TRNS,
		KC_TRNS, KC_EQL, KC_0, KC_1, KC_2, KC_3, KC_DOT, KC_0, KC_1, KC_2, KC_3, KC_DOT, KC_EQL, KC_ENT, KC_TRNS,
		KC_TRNS, KC_TRNS, KC_SLSH, KC_ASTR, KC_MINS, KC_PLUS, KC_NO, KC_SLSH, KC_ASTR, KC_MINS, KC_PLUS, KC_NO, KC_TRNS, KC_TRNS, KC_TRNS,
		KC_TRNS, KC_TRNS, KC_TRNS, TG(1), KC_TAB, KC_ENT, KC_TAB, KC_MPRV, KC_MUTE, KC_MNXT, KC_TRNS, KC_TRNS, KC_TRNS, KC_TRNS),

	KEYMAP(
		KC_TRNS, KC_TRNS, KC_TRNS, KC_TRNS, KC_TRNS, KC_TRNS, KC_TRNS, KC_TRNS, KC_TRNS, KC_TRNS, KC_TRNS, KC_TRNS, KC_TRNS, KC_TRNS, KC_TRNS,
		KC_TRNS, KC_TRNS, KC_TRNS, KC_TRNS, KC_TRNS, KC_TRNS, KC_TRNS, KC_TRNS, KC_TRNS, KC_TRNS, KC_TRNS, KC_TRNS, KC_TRNS, KC_TRNS, KC_TRNS,
		KC_TRNS, KC_TRNS, KC_TRNS, KC_TRNS, KC_TRNS, KC_TRNS, KC_TRNS, KC_TRNS, KC_TRNS, KC_TRNS, KC_TRNS, KC_TRNS, KC_TRNS, KC_TRNS, KC_TRNS,
		KC_TRNS, KC_TRNS, KC_TRNS, KC_TRNS, KC_TRNS, KC_TRNS, KC_TRNS, KC_TRNS, KC_TRNS, KC_TRNS, KC_TRNS, KC_TRNS, KC_TRNS, KC_TRNS, KC_TRNS,
		KC_TRNS, KC_TRNS, KC_TRNS, KC_TRNS, KC_TRNS, KC_TRNS, KC_TRNS, KC_TRNS, KC_TRNS, KC_TRNS, KC_TRNS, KC_TRNS, KC_TRNS, KC_TRNS),

	KEYMAP(
		KC_TRNS, KC_TRNS, KC_TRNS, KC_TRNS, KC_TRNS, KC_TRNS, KC_TRNS, KC_TRNS, KC_TRNS, KC_TRNS, KC_TRNS, KC_TRNS, KC_TRNS, KC_TRNS, KC_TRNS,
		KC_TRNS, KC_TRNS, KC_TRNS, KC_TRNS, KC_TRNS, KC_TRNS, KC_TRNS, KC_TRNS, KC_TRNS, KC_TRNS, KC_TRNS, KC_TRNS, KC_TRNS, KC_TRNS, KC_TRNS,
		KC_TRNS, KC_TRNS, KC_TRNS, KC_TRNS, KC_TRNS, KC_TRNS, KC_TRNS, KC_TRNS, KC_TRNS, KC_TRNS, KC_TRNS, KC_TRNS, KC_TRNS, KC_TRNS, KC_TRNS,
		KC_TRNS, KC_TRNS, KC_TRNS, KC_TRNS, KC_TRNS, KC_TRNS, KC_TRNS, KC_TRNS, KC_TRNS, KC_TRNS, KC_TRNS, KC_TRNS, KC_TRNS, KC_TRNS, KC_TRNS,
		KC_TRNS, KC_TRNS, KC_TRNS, KC_TRNS, KC_TRNS, KC_TRNS, KC_TRNS, KC_TRNS, KC_TRNS, KC_TRNS, KC_TRNS, KC_TRNS, KC_TRNS, KC_TRNS),

	KEYMAP(
		KC_TRNS, KC_TRNS, KC_TRNS, KC_TRNS, KC_TRNS, KC_TRNS, KC_TRNS, KC_TRNS, KC_TRNS, KC_TRNS, KC_TRNS, KC_TRNS, KC_TRNS, KC_TRNS, KC_TRNS,
		KC_TRNS, KC_TRNS, KC_TRNS, KC_TRNS, KC_TRNS, KC_TRNS, KC_TRNS, KC_TRNS, KC_TRNS, KC_TRNS, KC_TRNS, KC_TRNS, KC_TRNS, KC_TRNS, KC_TRNS,
		KC_TRNS, KC_TRNS, KC_TRNS, KC_TRNS, KC_TRNS, KC_TRNS, KC_TRNS, KC_TRNS, KC_TRNS, KC_TRNS, KC_TRNS, KC_TRNS, KC_TRNS, KC_TRNS, KC_TRNS,
		KC_TRNS, KC_TRNS, KC_TRNS, KC_TRNS, KC_TRNS, KC_TRNS, KC_TRNS, KC_TRNS, KC_TRNS, KC_TRNS, KC_TRNS, KC_TRNS, KC_TRNS, KC_TRNS, KC_TRNS,
		KC_TRNS, KC_TRNS, KC_TRNS, KC_TRNS, KC_TRNS, KC_TRNS, KC_TRNS, KC_TRNS, KC_TRNS, KC_TRNS, KC_TRNS, KC_TRNS, KC_TRNS, KC_TRNS),

	KEYMAP(
		KC_TRNS, KC_TRNS, KC_TRNS, KC_TRNS, KC_TRNS, KC_TRNS, KC_TRNS, KC_TRNS, KC_TRNS, KC_TRNS, KC_TRNS, KC_TRNS, KC_TRNS, KC_TRNS, KC_TRNS,
		KC_TRNS, KC_TRNS, KC_TRNS, KC_TRNS, KC_TRNS, KC_TRNS, KC_TRNS, KC_TRNS, KC_TRNS, KC_TRNS, KC_TRNS, KC_TRNS, KC_TRNS, KC_TRNS, KC_TRNS,
		KC_TRNS, KC_TRNS, KC_TRNS, KC_TRNS, KC_TRNS, KC_TRNS, KC_TRNS, KC_TRNS, KC_TRNS, KC_TRNS, KC_TRNS, KC_TRNS, KC_TRNS, KC_TRNS, KC_TRNS,
		KC_TRNS, KC_TRNS, KC_TRNS, KC_TRNS, KC_TRNS, KC_TRNS, KC_TRNS, KC_TRNS, KC_TRNS, KC_TRNS, KC_TRNS, KC_TRNS, KC_TRNS, KC_TRNS, KC_TRNS,
		KC_TRNS, KC_TRNS, KC_TRNS, KC_TRNS, KC_TRNS, KC_TRNS, KC_TRNS, KC_TRNS, KC_TRNS, KC_TRNS, KC_TRNS, KC_TRNS, KC_TRNS, KC_TRNS),

	KEYMAP(
		KC_TRNS, KC_TRNS, KC_TRNS, KC_TRNS, KC_TRNS, KC_TRNS, KC_TRNS, KC_TRNS, KC_TRNS, KC_TRNS, KC_TRNS, KC_TRNS, KC_TRNS, KC_TRNS, KC_TRNS,
		KC_TRNS, KC_TRNS, KC_TRNS, KC_TRNS, KC_TRNS, KC_TRNS, KC_TRNS, KC_TRNS, KC_TRNS, KC_TRNS, KC_TRNS, KC_TRNS, KC_TRNS, KC_TRNS, KC_TRNS,
		KC_TRNS, KC_TRNS, KC_TRNS, KC_TRNS, KC_TRNS, KC_TRNS, KC_TRNS, KC_TRNS, KC_TRNS, KC_TRNS, KC_TRNS, KC_TRNS, KC_TRNS, KC_TRNS, KC_TRNS,
		KC_TRNS, KC_TRNS, KC_TRNS, KC_TRNS, KC_TRNS, KC_TRNS, KC_TRNS, KC_TRNS, KC_TRNS, KC_TRNS, KC_TRNS, KC_TRNS, KC_TRNS, KC_TRNS, KC_TRNS,
		KC_TRNS, KC_TRNS, KC_TRNS, KC_TRNS, KC_TRNS, KC_TRNS, KC_TRNS, KC_TRNS, KC_TRNS, KC_TRNS, KC_TRNS, KC_TRNS, KC_TRNS, KC_TRNS),

	KEYMAP(
		KC_TRNS, KC_TRNS, KC_TRNS, KC_TRNS, KC_TRNS, KC_TRNS, KC_TRNS, KC_TRNS, KC_TRNS, KC_TRNS, KC_TRNS, KC_TRNS, KC_TRNS, KC_TRNS, KC_TRNS,
		KC_TRNS, KC_TRNS, KC_TRNS, KC_TRNS, KC_TRNS, KC_TRNS, KC_TRNS, KC_TRNS, KC_TRNS, KC_TRNS, KC_TRNS, KC_TRNS, KC_TRNS, KC_TRNS, KC_TRNS,
		KC_TRNS, KC_TRNS, KC_TRNS, KC_TRNS, KC_TRNS, KC_TRNS, KC_TRNS, KC_TRNS, KC_TRNS, KC_TRNS, KC_TRNS, KC_TRNS, KC_TRNS, KC_TRNS, KC_TRNS,
		KC_TRNS, KC_TRNS, KC_TRNS, KC_TRNS, KC_TRNS, KC_TRNS, KC_TRNS, KC_TRNS, KC_TRNS, KC_TRNS, KC_TRNS, KC_TRNS, KC_TRNS, KC_TRNS, KC_TRNS,
		KC_TRNS, KC_TRNS, KC_TRNS, KC_TRNS, KC_TRNS, KC_TRNS, KC_TRNS, KC_TRNS, KC_TRNS, KC_TRNS, KC_TRNS, KC_TRNS, KC_TRNS, KC_TRNS),

	KEYMAP(
		KC_TRNS, KC_TRNS, KC_TRNS, KC_TRNS, KC_TRNS, KC_TRNS, KC_TRNS, KC_TRNS, KC_TRNS, KC_TRNS, KC_TRNS, KC_TRNS, KC_TRNS, KC_TRNS, KC_TRNS,
		KC_TRNS, KC_TRNS, KC_TRNS, KC_TRNS, KC_TRNS, KC_TRNS, KC_TRNS, KC_TRNS, KC_TRNS, KC_TRNS, KC_TRNS, KC_TRNS, KC_TRNS, KC_TRNS, KC_TRNS,
		KC_TRNS, KC_TRNS, KC_TRNS, KC_TRNS, KC_TRNS, KC_TRNS, KC_TRNS, KC_TRNS, KC_TRNS, KC_TRNS, KC_TRNS, KC_TRNS, KC_TRNS, KC_TRNS, KC_TRNS,
		KC_TRNS, KC_TRNS, KC_TRNS, KC_TRNS, KC_TRNS, KC_TRNS, KC_TRNS, KC_TRNS, KC_TRNS, KC_TRNS, KC_TRNS, KC_TRNS, KC_TRNS, KC_TRNS, KC_TRNS,
		KC_TRNS, KC_TRNS, KC_TRNS, KC_TRNS, KC_TRNS, KC_TRNS, KC_TRNS, KC_TRNS, KC_TRNS, KC_TRNS, KC_TRNS, KC_TRNS, KC_TRNS, KC_TRNS),

	KEYMAP(
		KC_TRNS, KC_TRNS, KC_TRNS, KC_TRNS, KC_TRNS, KC_TRNS, KC_TRNS, KC_TRNS, KC_TRNS, KC_TRNS, KC_TRNS, KC_TRNS, KC_TRNS, KC_TRNS, KC_TRNS,
		KC_TRNS, KC_TRNS, KC_TRNS, KC_TRNS, KC_TRNS, KC_TRNS, KC_TRNS, KC_TRNS, KC_TRNS, KC_TRNS, KC_TRNS, KC_TRNS, KC_TRNS, KC_TRNS, KC_TRNS,
		KC_TRNS, KC_TRNS, KC_TRNS, KC_TRNS, KC_TRNS, KC_TRNS, KC_TRNS, KC_TRNS, KC_TRNS, KC_TRNS, KC_TRNS, KC_TRNS, KC_TRNS, KC_TRNS, KC_TRNS,
		KC_TRNS, KC_TRNS, KC_TRNS, KC_TRNS, KC_TRNS, KC_TRNS, KC_TRNS, KC_TRNS, KC_TRNS, KC_TRNS, KC_TRNS, KC_TRNS, KC_TRNS, KC_TRNS, KC_TRNS,
		KC_TRNS, KC_TRNS, KC_TRNS, KC_TRNS, KC_TRNS, KC_TRNS, KC_TRNS, KC_TRNS, KC_TRNS, KC_TRNS, KC_TRNS, KC_TRNS, KC_TRNS, KC_TRNS),
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

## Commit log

2021-04-11 kicad footprints
2021-04-11 update code for case
2021-06-03 updated rect case files
2021-06-03 case files
